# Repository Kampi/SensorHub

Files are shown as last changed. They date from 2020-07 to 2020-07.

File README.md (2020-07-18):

# SensorHub

## Table of Contents

- [SensorHub](#sensorhub)
  - [Table of Contents](#table-of-contents)
  - [About](#about)
  - [Image sources](#image-sources)
  - [Setup](#setup)
  - [Device modes](#device-modes)
  - [Bluetooth](#bluetooth)
  - [Measurement](#measurement)
  - [History](#history)
  - [Maintainer](#maintainer)

## About

Solar-powered, low energy environment sensor node with WiFi interface. The device will measure the following parameter:

- Temperature (with a [MCP9808](http://ww1.microchip.com/downloads/en/DeviceDoc/25095A.pdf))
- Humidity (with a [BME680](https://www.bosch-sensortec.com/media/boschsensortec/downloads/datasheets/bst-bme680-ds001.pdf))
- Pressure (with a [BME680](https://www.bosch-sensortec.com/media/boschsensortec/downloads/datasheets/bst-bme680-ds001.pdf))
- Gas resistance (with a [BME680](https://www.bosch-sensortec.com/media/boschsensortec/downloads/datasheets/bst-bme680-ds001.pdf))
- Ambient light (with a [BH1726](https://fscdn.rohm.com/en/products/databook/datasheet/ic/sensor/light/bh1726nuc-e.pdf))
- UV (with a [VEML6070](https://www.vishay.com/docs/84277/veml6070.pdf))

The whole device is designed for low power operation and for a solar panel as current source. A backup battery will be used to buffer the sun-free time during the night or on cloudy days.
This battery will be charged by an integrated solar-charging circuit.

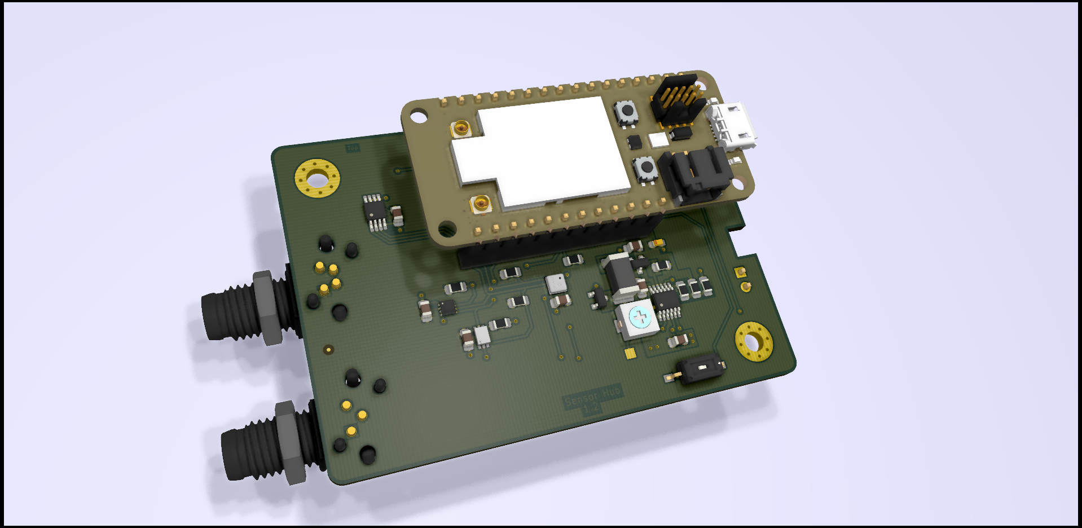
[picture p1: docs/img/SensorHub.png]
Overview


The integrated WiFi is used to transmit the data as an [MQTT](http://mqtt.org/) message to a broker (i. e. a Raspberry Pi). The included Qt application for the Raspberry Pi can be used to visualize and record the received data.

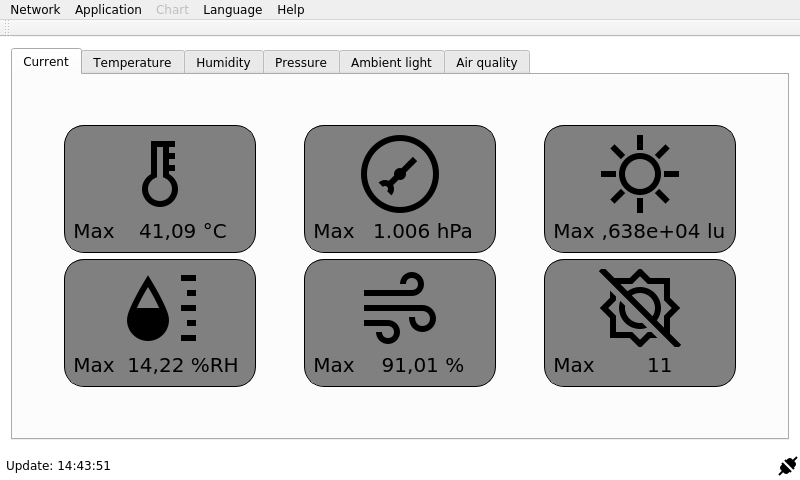
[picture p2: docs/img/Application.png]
Application


Please visit the [project site](https://www.kampis-elektroecke.de/wetterdaten-aufzeichnen/) or write me an [e-mail](mailto:DanielKampert@kampis-elektroecke.de) when you need additional informations or if you have any questions.

## Image sources

- [Language Icons](https://www.iconfinder.com/iconsets/flags_gosquared)
- [Icons8](https://icons8.com/icon/set/database/material)
- [Qt project](https://www.qt.io/blog/2016/06/20/introducing-new-built-with-qt-logo)

## Setup

- You have to use the [Particle CLI](https://docs.particle.io/reference/developer-tools/cli/) or the [Particle App](https://play.google.com/store/apps/details?id=io.particle.android.app&hl=de) to setup your WiFi credentials in the microcontroller module before you can use the software.

```bash
$ particle usb start-listening
Done.

$ particle serial wifi
? Should I scan for nearby Wi-Fi networks? (Y/n) y
? Should I scan for nearby Wi-Fi networks? Yes
? SSID ...
? SSID ...
? Security Type (Use arrow keys)
? Security Type ...
? Cipher Type (Use arrow keys)
? Cipher Type ...
? Wi-Fi Password ...
? Wi-Fi Password ...
Done! Your device should now restart.
```

- Download a bluetooth app for your smartphone (i. e. [nRF Connect](https://play.google.com/store/apps/details?id=no.nordicsemi.android.mcp&hl=de)).
- Make sure that your microcontroller module runs at least firmware version [1.5.2](https://github.com/particle-iot/device-os/releases/tag/v1.5.2).
- **Optional:** Build the firmware from the soures in `software/SensorHub` by using [Visual Studio Code](https://code.visualstudio.com/) and the [Particle Workbench](https://www.particle.io/workbench/).
- Power up the `SensorHub` and flash the firmware from `software/release` by using the [Particle CLI](https://docs.particle.io/tutorials/developer-tools/cli/#flashing-over-serial-for-the-electron).
- Hold the `MODE` button of the microcontroller module to enter the setup mode.
- After entering the setup mode the RGB LED of the device will lights up red.
- Open the app and connect your smartphone with the `SensorHub`. When the connection is successful the RGB LED of the `SensorHub` starts to blink green until you close the connection or a IP address of the MQTT broker was transmitted successfully.

## Device modes

The `SensorHub` use the RGB led of the microcontroller module to display his current state. Each state is encoded in a blink pattern which begins with a **3 seconds** group color.

| **RGB color** | **Group** |
|:---:|:---:|
| Blue | Sensors |
| Green | Network |
| Red | Device |

The group color is followed by the error code which is encoded with a white flashing of the RGB LED. Each flash has a duration of **1 second**.

| **Blink code** | **Sensors** | **Network** | **Device** |
|:---:|:---:|:---:|:---:|
| 1x | Temperature sensor failure. | No valid WiFi credentials found. <br> Please use the [Particle CLI](https://docs.particle.io/reference/developer-tools/cli/) to setup your WiFi credentials. | - |
| 2x | Light sensor failure. | No valid IP address found. | - |
| 3x | Environment sensor failure. | Connection error. | - |
| 4x | UV sensor failure. | Network timeout. | - |
| 5x | Communication error. | - | - |

The current device error is also printed over the serial interface of the microcontroller module or is published over the MQTT tag `sensorhub/errors` (this required valid network settings).

## Bluetooth

The firmware use the following UUIDs for the bluetooth low energy service:

| **UUID** | **Description** |
|:---:|:---:|
| b4250401-fb4b-4746-b2b0-93f0e61122c6 | General service UUID for the BLE service. |
| b4250402-fb4b-4746-b2b0-93f0e61122c6 | Server IP UUID to configure the IP address of the MQTT server. |

## Measurement

After a successful configuration and initialization the device will enter the sleep mode. The microcontroller is woken up every three minutes to read in new data from the sensors. After a successful read of the
sensors the data gets packed in a [JSON](https://www.json.org/json-en.html) structure and published by using the [MQTT](http://mqtt.org/) protocol. The firmware uses the topic `sensorhub/weather` to publish the sensor data in the network.
The JSON object uses the following structure:

```json
{
  "Temperature": "23.0",
  "Ambient light": "1000.0",
  "UV": "7",
  "Pressure": "1004",
  "Humidity": "44.0",
  "Gas resistance": "20000",
  "Gas valid": "0",
  "IAQ": "97.5",
  "IAQ valid": "0",
  "Solar": "1.2",
  "Battery": "3.3"
}
```

| **Element** | **Description** |
|:---:|:---:|
| Temperature | Temperature as float in °C. |
| Ambient light  | Illuminance as float in lux. |
| UV | UV-A index as byte in the range of 0 to 11. |
| Pressure | Air pressure as float in hPa. |
| Humidity | Humidity as float in %RH. |
| Gas resistance | Gas resistance as float in Ohms. |
| Gas valid | Boolean flag to indicate a valid gas measurement. |
| IAQ | [Indor Air Quality](https://en.wikipedia.org/wiki/Indoor_air_quality) in %. |
| IAQ valid | Boolean flag to indicate a valid IAQ index. |
| Solar | Solar cell voltage as float in V. |
| Battery | Battery voltage as float in V. |

## History

| **Version** | **Description** | **Date** |
|---|---|---|
| 0.1 | Release hardware version 1.1 <br> Firmware version 1.0 <br> Release application version 1.0 | 13.07.2020 |
| 0.2 | Release hardware version 1.2 <br> Improve firmware and release firmware 1.1 <br> Release application version 1.1 | 18.07.2020 |

## Maintainer

- [Daniel Kampert](mailto:DanielKampert@kampis-elektroecke.de)

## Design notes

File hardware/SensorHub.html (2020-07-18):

# SensorHub

From: 18.05.2020 15:43:41

Component Count: 35

Ref | Qnty | Value | Footprint | Description | Mfr. | Mfr. Part Nr. | Mouser
C1, C3 | 2 | 1uF | C_0805_2012Metric_Pad1.15x1.40mm_HandSolder | Unpolarized capacitor | Kemet | C0805X105K3RAC3316 | 80-C0805X105K3R3316
C2, C6, C7, C8 | 4 | 100nF | C_0805_2012Metric_Pad1.15x1.40mm_HandSolder | Unpolarized capacitor | Kemet | C0805C104K5RAC7411 | 80-C0805C104K5RACLR
C4, C9 | 2 | 10uF | C_0805_2012Metric_Pad1.15x1.40mm_HandSolder | Unpolarized capacitor | TDK | C2012X7S1E106K125AE | 810-C2012X7S1E106125
C5 | 1 | 100uF | CP_EIA-1608-08_AVX-J_Pad1.25x1.05mm_HandSolder | Polarized capacitor | AVX | F980J107MMAAXE | 581-F980J107MMAAXE
D1, D2 | 2 | ZLLS500 | D_SOT-23_ANK | Schottky diode | Diodes Incorporated | ZLLS500TA | 522-ZLLS500TA
IC1 | 1 | BQ32000 | SOIC-8_3.9x4.9mm_P1.27mm | Serial, I2C Real-time clock, Trickle charger, 3V to 3.6V VCC, -40°C to +85°C, SOIC-8 | Texas Instruments | BQ32000DR | 595-BQ32000DR
IC2 | 1 | LT3652EMSE | MSOP-12-1EP_3x4mm_P0.65mm_EP1.65x2.85mm | Step-down battery charger, Lithium Phosphate ( LiFePO4), Lead (Pb), Lithium+ (Li+) , 4.95V to 32V VDD, -40 to +125 degree Celcius, MSOP-12 | Analog Devices | LT3652EMSE#PBF | 584-LT3652EMSE#PBF
IC3 | 1 | BME680 | Bosch_LGA-8_3x3mm_P0.8mm_ClockwisePinNumbering | 4-in-1 sensor, gas, humidity, pressure, temperature, I2C and SPI interface, 1.71-3.6V, LGA-8 | Bosch Sensortec | BMP680 | 262-BME680
IC4 | 1 | BH1726 | Texas_S-PWSON-N8_EP1.2x2mm | | Rohm Semiconductor | BH1726NUC-E2 | 755-BH1726NUC-E2
IC5 | 1 | MCP9808 | MSOP-8_3x3mm_P0.65mm | ±0.5°C Maximum Accuracy I2C Temperature Sensor. | Microchip | MCP9808T-E/MS | 579-MCP9808T-E/MS
L1 | 1 | 68uH | L_2512_6332Metric_Pad1.52x3.35mm_HandSolder | Inductor | Vishay / Dale | IHLP2525CZER100M11 | 70-IHLP2525CZER100M1
M1 | 1 | ParticleArgon | ParticleArgon | | Particle | ARGNKIT | 465-ARGNKIT
R1, R2 | 2 | 10k | R_0805_2012Metric_Pad1.15x1.40mm_HandSolder | Resistor | TE Connectivity | CRGP0805F10K | 279-CRGP0805F10K
R3 | 1 | NTC | PinHeader_1x02_P2.54mm_Vertical | Resistor | Murata Electronics | NXRT15XH103FA5B040 | 81-NXRT15XH103FA5B040
R4, R6 | 2 | 220k | R_0805_2012Metric_Pad1.15x1.40mm_HandSolder | Resistor | TE Connectivity | CRGP0805F220K | 279-CRGP0805F220K
R5 | 1 | 47k | R_0805_2012Metric_Pad1.15x1.40mm_HandSolder | Resistor | TE Connectivity | CRGP0805F47K | 279-CRGP0805F47K
R7 | 1 | 0R22 | R_0805_2012Metric_Pad1.15x1.40mm_HandSolder | Resistor | Panasonic | ERJ-U6QJR22V | 667-ERJ-U6QJR22V
R8, R9 | 2 | NB | R_0805_2012Metric_Pad1.15x1.40mm_HandSolder | Resistor
R10, R11, R12 | 3 | 3k3 | R_0805_2012Metric_Pad1.15x1.40mm_HandSolder | Resistor | TE Connectivity | CRGP0805F3K3 | 279-CRGP0805F3K3
RV1 | 1 | 10k | Potentiometer_Vishay_TS53YJ_Vertical | Potentiometer | Vishay | TS53YJ103MR10 | 72-TS53YJ-10K
SW1 | 1 | ENABLE | SW_DIP_SPSTx01_Slide_Omron_A6S-110x_W8.9mm_P2.54mm | 1x DIP Switch, Single Pole Single Throw (SPST) switch, small symbol | Omron | A6S-1104-PH | 653-A6S1104PH
X1 | 1 | WIND | 3-2172067-2 | Generic connector, single row, 01x04, script generated (kicad-library-utils/schlib/autogen/connector/) | TE Connectivity | 3-2172067-2 | 571-3-2172067-2
X2 | 1 | SOLAR | 2-2172067-2 | Generic connector, single row, 01x03, script generated (kicad-library-utils/schlib/autogen/connector/) | TE Connectivity | 2-2172067-2 | 571-2-2172067-2
Y1 | 1 | 32kHz | Crystal_SMD_SeikoEpson_MC306-4Pin_8.0x3.2mm | Two pin crystal | Epson Timing | MC-306 32.7680K-A3:ROHS | 732-MC306-32.7KA3R

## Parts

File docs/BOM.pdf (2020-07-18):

## Stückliste Bill of Materials

Nummer Number | Bezeichnung Description | Wert Value | Gehäuse Case | Hersteller Manufacturer | Herstellerbezeichnung Manufacturer's designation | Lieferant Distributor | Bestellnummer Order number | Anzahl Quantity
C3 | Unpolarized capacitor | 1uF | C_0805_2012Metric_Pad1.15x1.40mm_HandSolder | Kemet | C0805X105K3RAC3316 | Mouser | 80-C0805X105K3R3316 | 1
C2, C6, C7, C8 | Unpolarized capacitor | 100nF | C_0805_2012Metric_Pad1.15x1.40mm_HandSolder | Kemet | C0805C104K5RAC7411 | Mouser | 80-C0805C104K5RACLR | 4
C4, C9 | Unpolarized capacitor | 10uF | C_0805_2012Metric_Pad1.15x1.40mm_HandSolder | TDK | C2012X7S1E106K125AE | Mouser | 810-C2012X7S1E106125 | 2
C5 | Polarized capacitor | 100uF | CP_EIA-1608-08_AVX-J_Pad1.25x1.05mm_HandSolder | AVX | F980J107MMAAXE | Mouser | 581-F980J107MMAAXE | 1
D1, D2 | Schottky diode | ZLLS500 | D_SOT-23_ANK | Diodes Incorporated | ZLLS500TA | Mouser | 522-ZLLS500TA | 2
IC1 | UVA sensor | VEML6070 | OPLGA-6 | Vishay Semiconductors | VEML6070 | Mouser | 78-VEML6070 | 1
IC2 | Step-down battery charger | LT3652EMSE | MSOP-12-1EP_3x4mm_P0.65mm_EP1.65x2.85mm | Analog Devices | LT3652EMSE#PBF | Mouser | 584-LT3652EMSE#PBF | 1
IC3 | 4-in-1 sensor, gas, humidity, pressure, temperature | BME680 | Bosch_LGA-8_3x3mm_P0.8mm_ClockwisePinNumbering | Bosch Sensortec | BMP680 | Mouser | 262-BME680 | 1
IC4 | Ambient light sensor | BH1726 | WSON-8-1EP_2x2mm_P0.5mm_EP0.9x1.6mm | Rohm Semiconductor | BH1726NUC-E2 | Mouser | 755-BH1726NUC-E2 | 1
IC5 | Temperature Sensor | MCP9808 | MSOP-8_3x3mm_P0.65mm | Microchip | MCP9808T-E/MS | Mouser | 579-MCP9808T-E/MS | 1
L1 | Inductor | 22uH | L_2512_6332Metric_Pad1.52x3.35mm_HandSolder | Vishay / Dale | IDC2512ER220M | Mouser | 70-IDC2512ER220M | 1
M1 | | ParticleArgon | ParticleArgon | Particle | ARGNKIT | Mouser | 465-ARGNKIT | 1
R1, R2 | Resistor | 10k | R_0805_2012Metric_Pad1.15x1.40mm_HandSolder | TE Connectivity | CRGP0805F10K | Mouser | 279-CRGP0805F10K | 2
R3 | Resistor | NTC | PinHeader_1x02_P2.54mm_Vertical | Murata Electronics | NXRT15XH103FA5B040 | Mouser | 81-NXRT15XH103FA5B40 | 1
R4 | Resistor | 205k ±1% | R_0805_2012Metric_Pad1.15x1.40mm_HandSolder | Rohm Semiconductor | KTR10EZPF2053 | Mouser | 755-KTR10EZPF2053 | 1
R5 | Resistor | 60k4 ±1% | R_0805_2012Metric_Pad1.15x1.40mm_HandSolder | Rohm Semiconductor | KTR10EZPF6042 | Mouser | 755-KTR10EZPF6042 | 1
R6 | Resistor | 220k ±1% | R_0805_2012Metric_Pad1.15x1.40mm_HandSolder | Bourns | CHV0805-FX-2203ELF | Mouser | 652-CHV0805FX2203ELF | 1
R7 | Resistor | 0R22 ±1% | R_0805_2012Metric_Pad1.15x1.40mm_HandSolder | Panasonic | ERJ-U6QJR22V | Mouser | 667-ERJ-U6QJR22V | 1
R8 | Resistor | 120k ±1% | R_0805_2012Metric_Pad1.15x1.40mm_HandSolder | Rohm Semiconductor | KTR10EZPF1203 | Mouser | 755-KTR10EZPF1203 | 1
R9 | Resistor | 20k5 ±1% | R_0805_2012Metric_Pad1.15x1.40mm_HandSolder | Rohm Semiconductor | KTR10EZPF2052 | Mouser | 755-KTR10EZPF2052 | 1
R10, R11, R12, R13, R14, R15 | Resistor | 3k3 | R_0805_2012Metric_Pad1.15x1.40mm_HandSolder | TE Connectivity | CRGP0805F3K3 | Mouser | 279-CRGP0805F3K3 | 6
R16 | Resistor | 270k | R_0805_2012Metric_Pad1.15x1.40mm_HandSolder | TE Connectivity | CRGP0805F270K | Mouser | 279-CRGP0805F270K | 1
RV1 | Potentiometer | 10k | Potentiometer_Vishay_TS53YJ_Vertical | Vishay | TS53YJ103MR10 | Mouser | 72-TS53YJ-10K | 1
SW1 | 1x DIP Switch, Single Pole | ENABLE | SW_DIP_SPSTx01_Slide_Omron_A6S-110x_W8.9mm_P2.54mm | Omron | A6S-1104-PH | Mouser | 653-A6S1104PH | 1
X1 | | WIND | 3-2172067-2 | TE Connectivity | 3-2172067-2 | Mouser | 571-3-2172067-2 | 1
X2 | | SOLAR | 2-2172067-2 | TE Connectivity | 2-2172067-2 | Mouser | 571-2-2172067-2 | 1

Legende / Legend:

Nicht bestückt | Not assembled
Durchsteckmontage | Through-Hole technology

18.07.2020

1.2

Bezeichnung / Name : Sensor Hub

Seite 1 von 4

18.07.2020

1.2

Bezeichnung Description | Hersteller Manufacturer | Herstellerbezeichnung Manufacturer's designation | Lieferant Distributor | Bestellnummer Order number | Anzahl Quantity
Gehäuse, Polycarbonat UL 94 V0, glasklarer Deckel | Bopla | B 080805 PC-V0-G 7024 | Bopla | B 080805 PC-V0-G 7024 | 1
Distanzhülse | Harwin | R30-6701494 | Mouser | 855-R30-6701494 | 2
Druckausgleichselemen | Bopla | DAE M6 7035 | Bopla | DAE M6 7035 | 1
Stecker, Female, 3-pol | TE Connectivity | T4010008031-000 | TE | T4010008031-000 | 1
Stecker, Female, 4-pol | TE Connectivity | T4010008041-000 | TE | T4010008041-000 | 1
Solarzelle | Offgridtec | 002960 | Solar Autark | 3-01-002960 | 1
Schraube M3x18 | | | Würth | SHR-ZYL-ISO14580-A2/70-TX10-M3X18 | 2
Mutter M6x0.75 | TE Connectivity | 1-1634816-0 | RS | 1-1634816-0 | 1

Legende / Legend:

Nicht bestückt | Not assembled

## Mechanische Komponenten Mechanical Components

Bezeichnung / Name: Sensor Hub

## Technische Spezifikationen Technical Specifications

18.07.2020

1.2

Bezeichnung Description | Spezifikation Specification
Abmaße Dimensions | 72 x 50 mm
Standard Standard | IPC-A-610 E Class 2 oder höher IPC-A-610 E Class 2 or higher
Basismaterial Base material | 1,5 mm FR4, 35 µmCu
Stopplack Soldermask | Beidseitig Grün Both sides green
Bestückungsdruck Silkscreen | Keiner None
Oberfläche Surface | Chemisch Nickel-Gold Chemical nickel-gold
Isolierlack Insulation varnish | Nein No
Min. Bohrdurchmesser Min. drill-end diameter | 0,2 mm
Min. Leiterbahnbreite Min track size | 0,25 mm
Min. Leiterbahnabstand Min track distance | 0,2 mm
Kantenmetallisierung Sideplating | Nein No
Freistellung Vias Clearance vias | Bohrlochdurchmesser + max. 0,15 mm gemäß ZVEI Drill hole + max. 0,15 mm regarding ZVEI
Kontur Contour | Gefräst oder geritzt gemäß DIN ISO 2768 mittel Milled or scored according DIN ISO 2768 medium

Bezeichnung / Name: Sensor Hub

## Bestückung Placement

18.07.2020

1.2
Nummer Number | Position X Position X | Position Y Position Y | Seite Side | Rotation Rotation
R8 | -50.419000 | 6.604000 | 0.000000 | bottom
R9 | -54.356000 | 6.604000 | 180.000000 | bottom
C2 | 21.844000 | 15.494000 | 270.000000 | top
C3 | 50.174400 | 18.021400 | 270.000000 | top
C4 | 51.181000 | 24.638000 | 180.000000 | top
C5 | 55.372000 | 24.638000 | 0.000000 | top
C6 | 17.002000 | 20.853400 | 90.000000 | top
C7 | 16.124860 | 36.051480 | 270.000000 | top
C8 | 37.068000 | 18.288000 | 180.000000 | top
C9 | 53.467000 | 8.636000 | 180.000000 | top
D1 | 43.053000 | 17.526000 | 0.000000 | top
D2 | 51.038000 | 21.717000 | 270.000000 | top
IC2 | 53.463700 | 15.125800 | 90.000000 | top
IC3 | 37.068000 | 21.082000 | 90.000000 | top
IC4 | 20.200000 | 20.561400 | 0.000000 | top
IC5 | 13.117860 | 37.139380 | 90.000000 | top
L1 | 46.974000 | 19.980200 | 270.000000 | top
R1 | 40.116000 | 29.426000 | 0.000000 | top
R2 | 35.823000 | 29.426000 | 180.000000 | top
R4 | 56.948800 | 16.245000 | 270.000000 | top
R5 | 59.064400 | 16.245000 | 90.000000 | top
R6 | 61.121800 | 16.245000 | 270.000000 | top
R7 | 54.864000 | 20.828000 | 180.000000 | top
R10 | 30.718000 | 24.130000 | 0.000000 | top
R11 | 30.727000 | 19.558000 | 0.000000 | top
R12 | 40.903000 | 24.384000 | 180.000000 | top
R13 | 44.196000 | 29.438600 | 180.000000 | top
R14 | 22.098000 | 23.368000 | 0.000000 | top
R15 | 28.702000 | 30.226000 | 270.000000 | top
R16 | 27.178000 | 16.764000 | 0.000000 | top
REF** | 3.000000 | 18.000000 | 0.000000 | top
REF** | 70.000000 | 48.000000 | 0.000000 | top

Bezeichnung / Name: Sensor Hub

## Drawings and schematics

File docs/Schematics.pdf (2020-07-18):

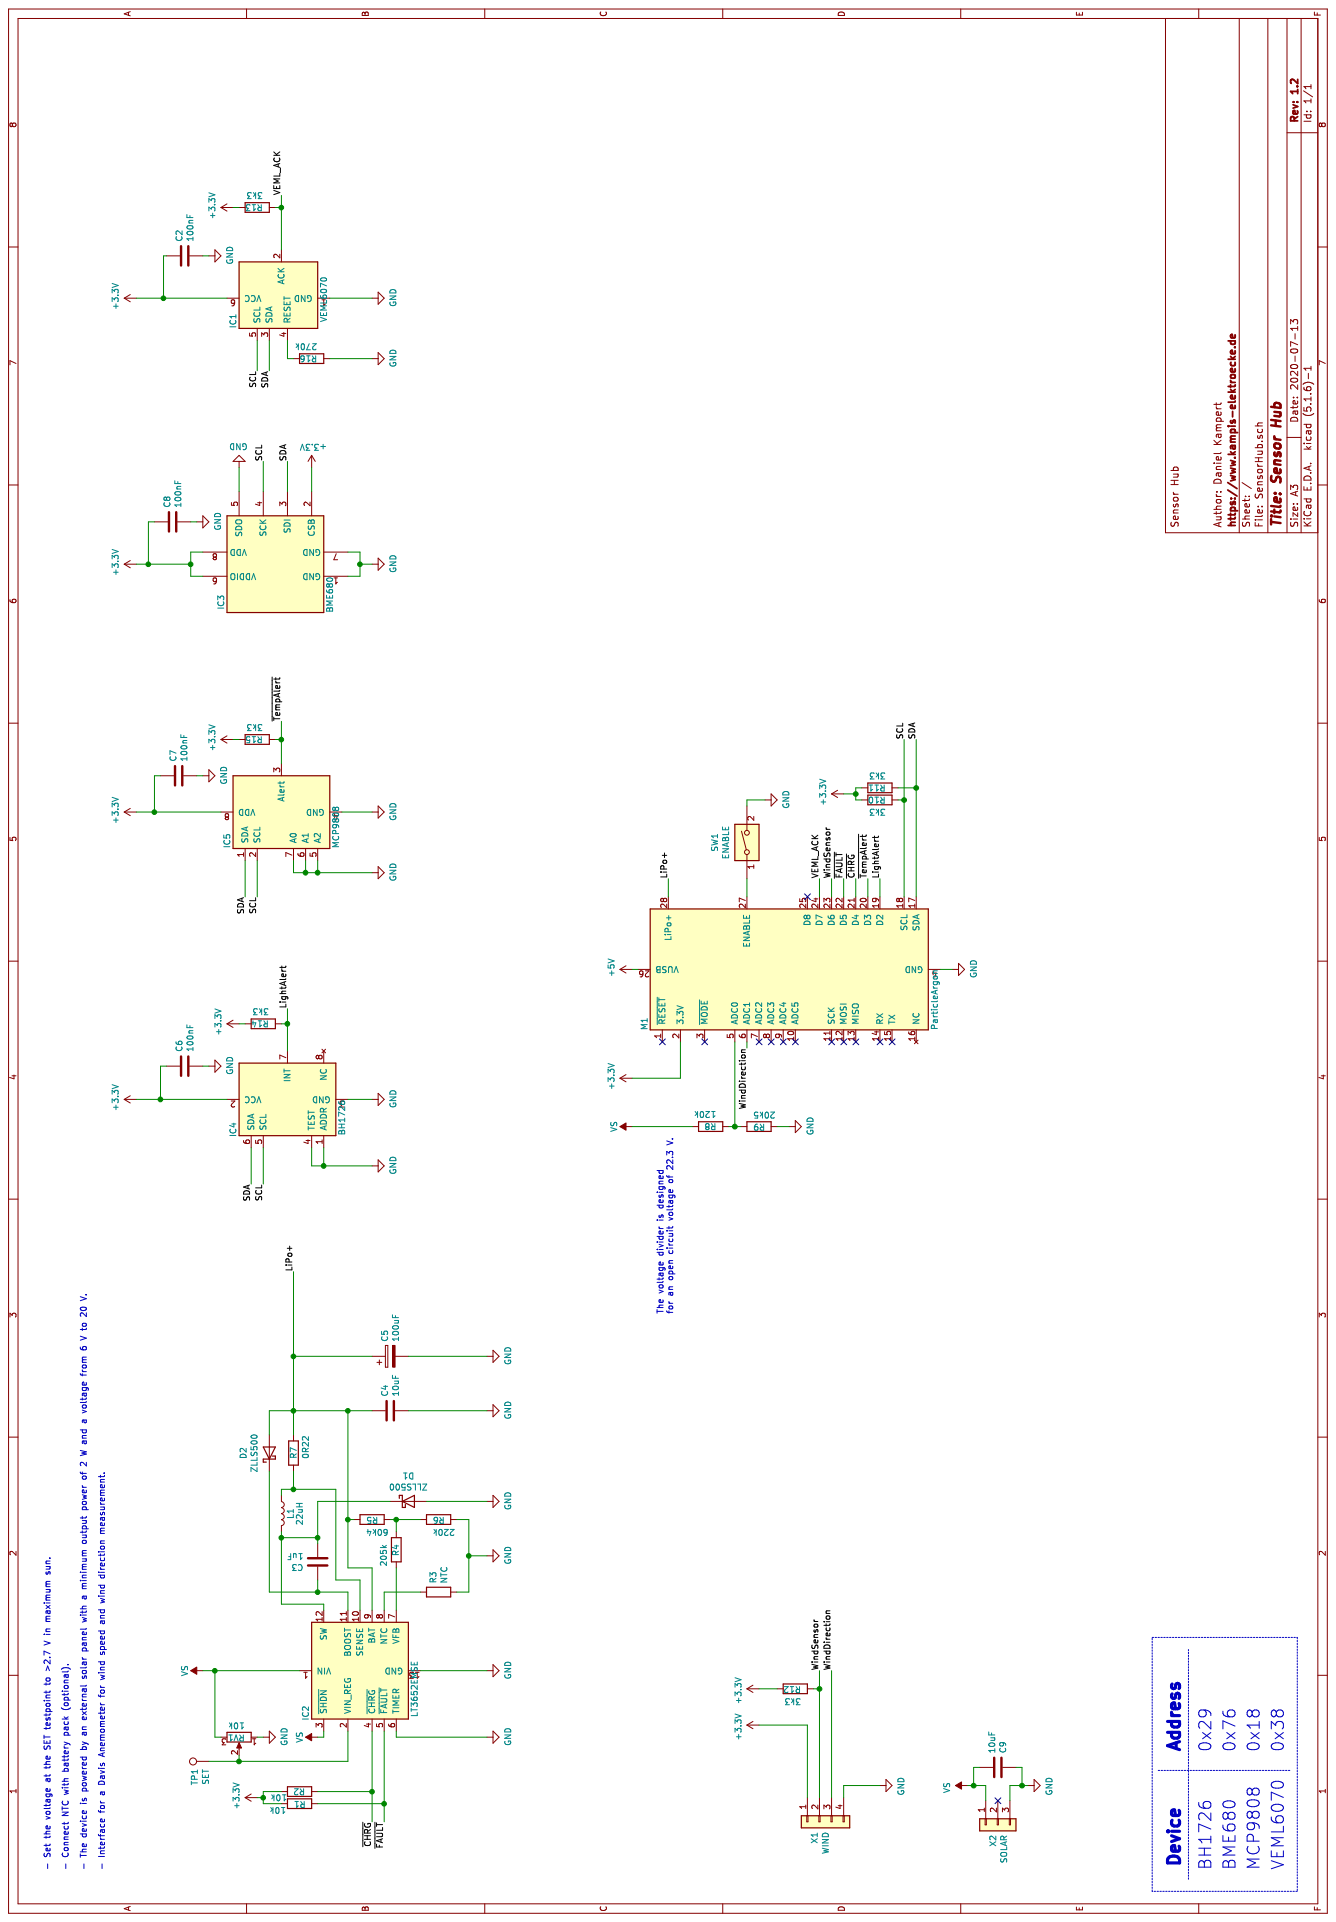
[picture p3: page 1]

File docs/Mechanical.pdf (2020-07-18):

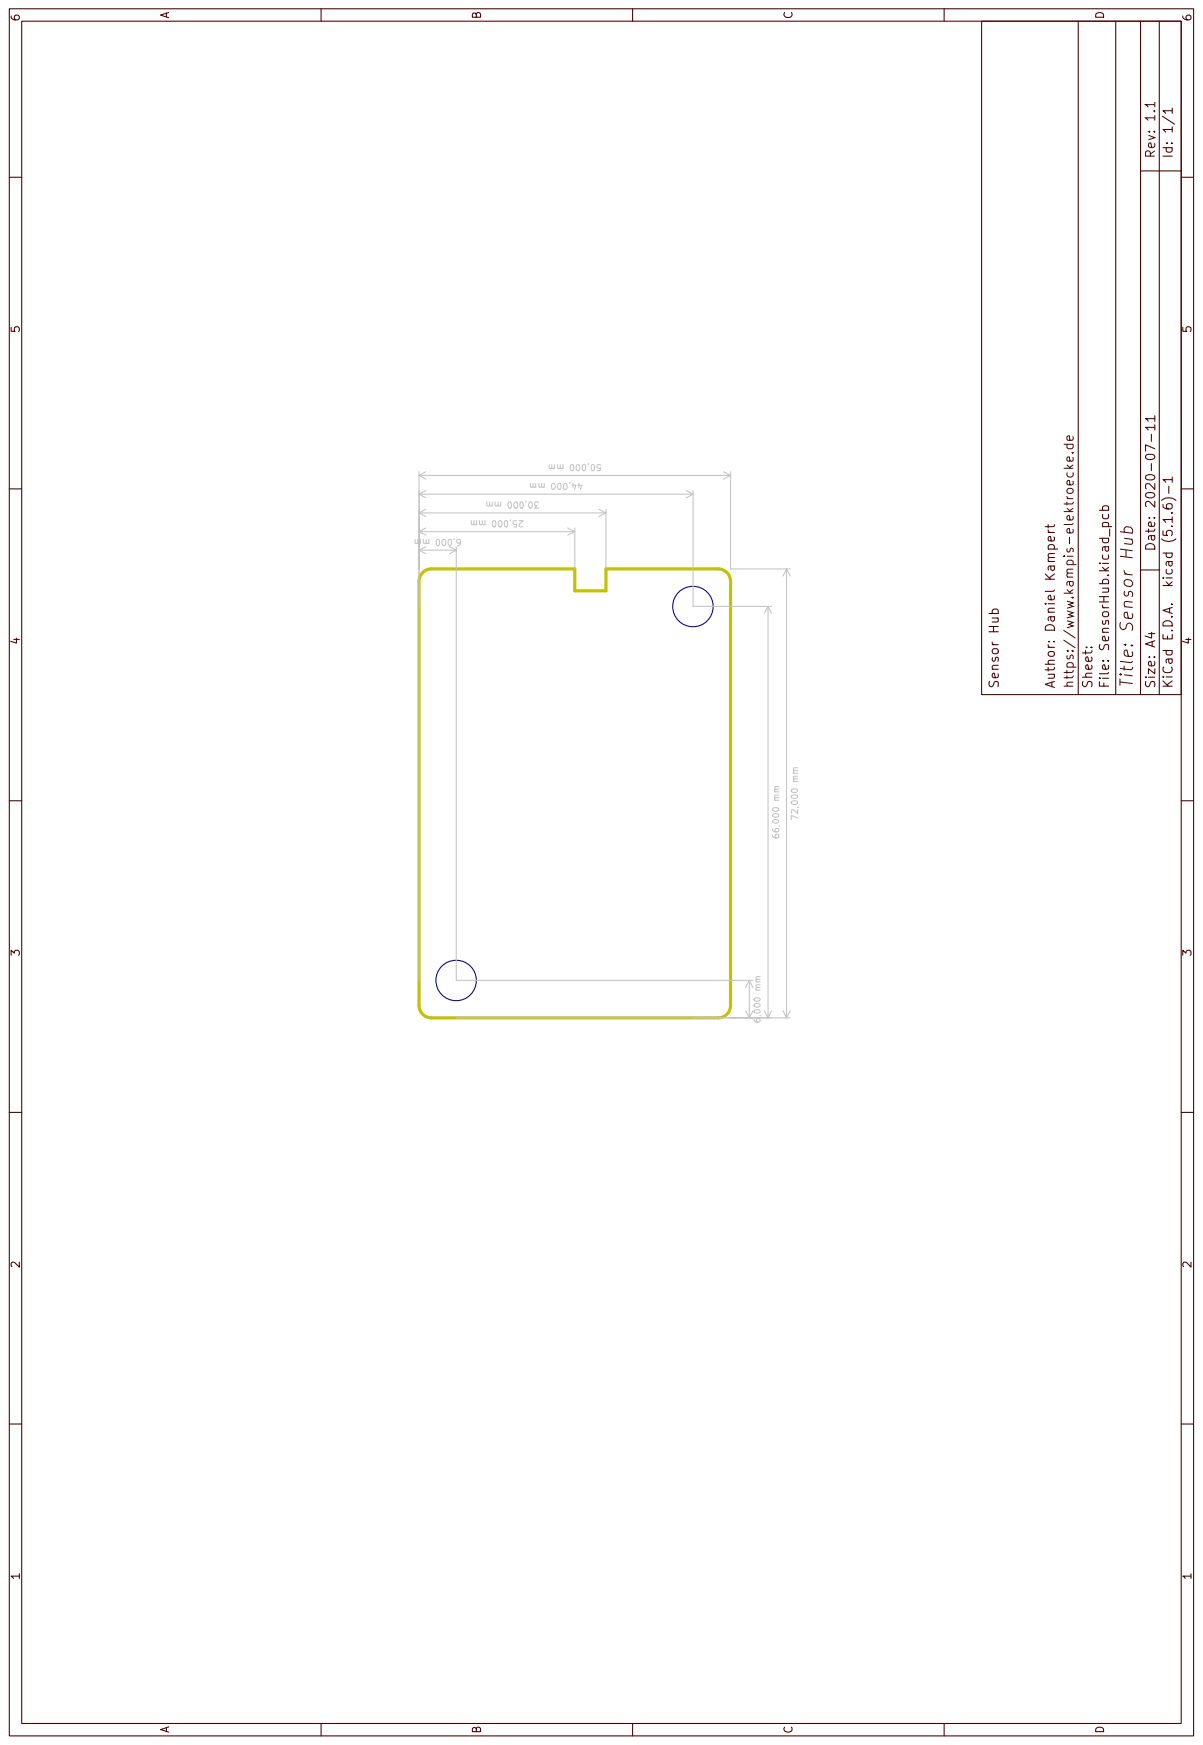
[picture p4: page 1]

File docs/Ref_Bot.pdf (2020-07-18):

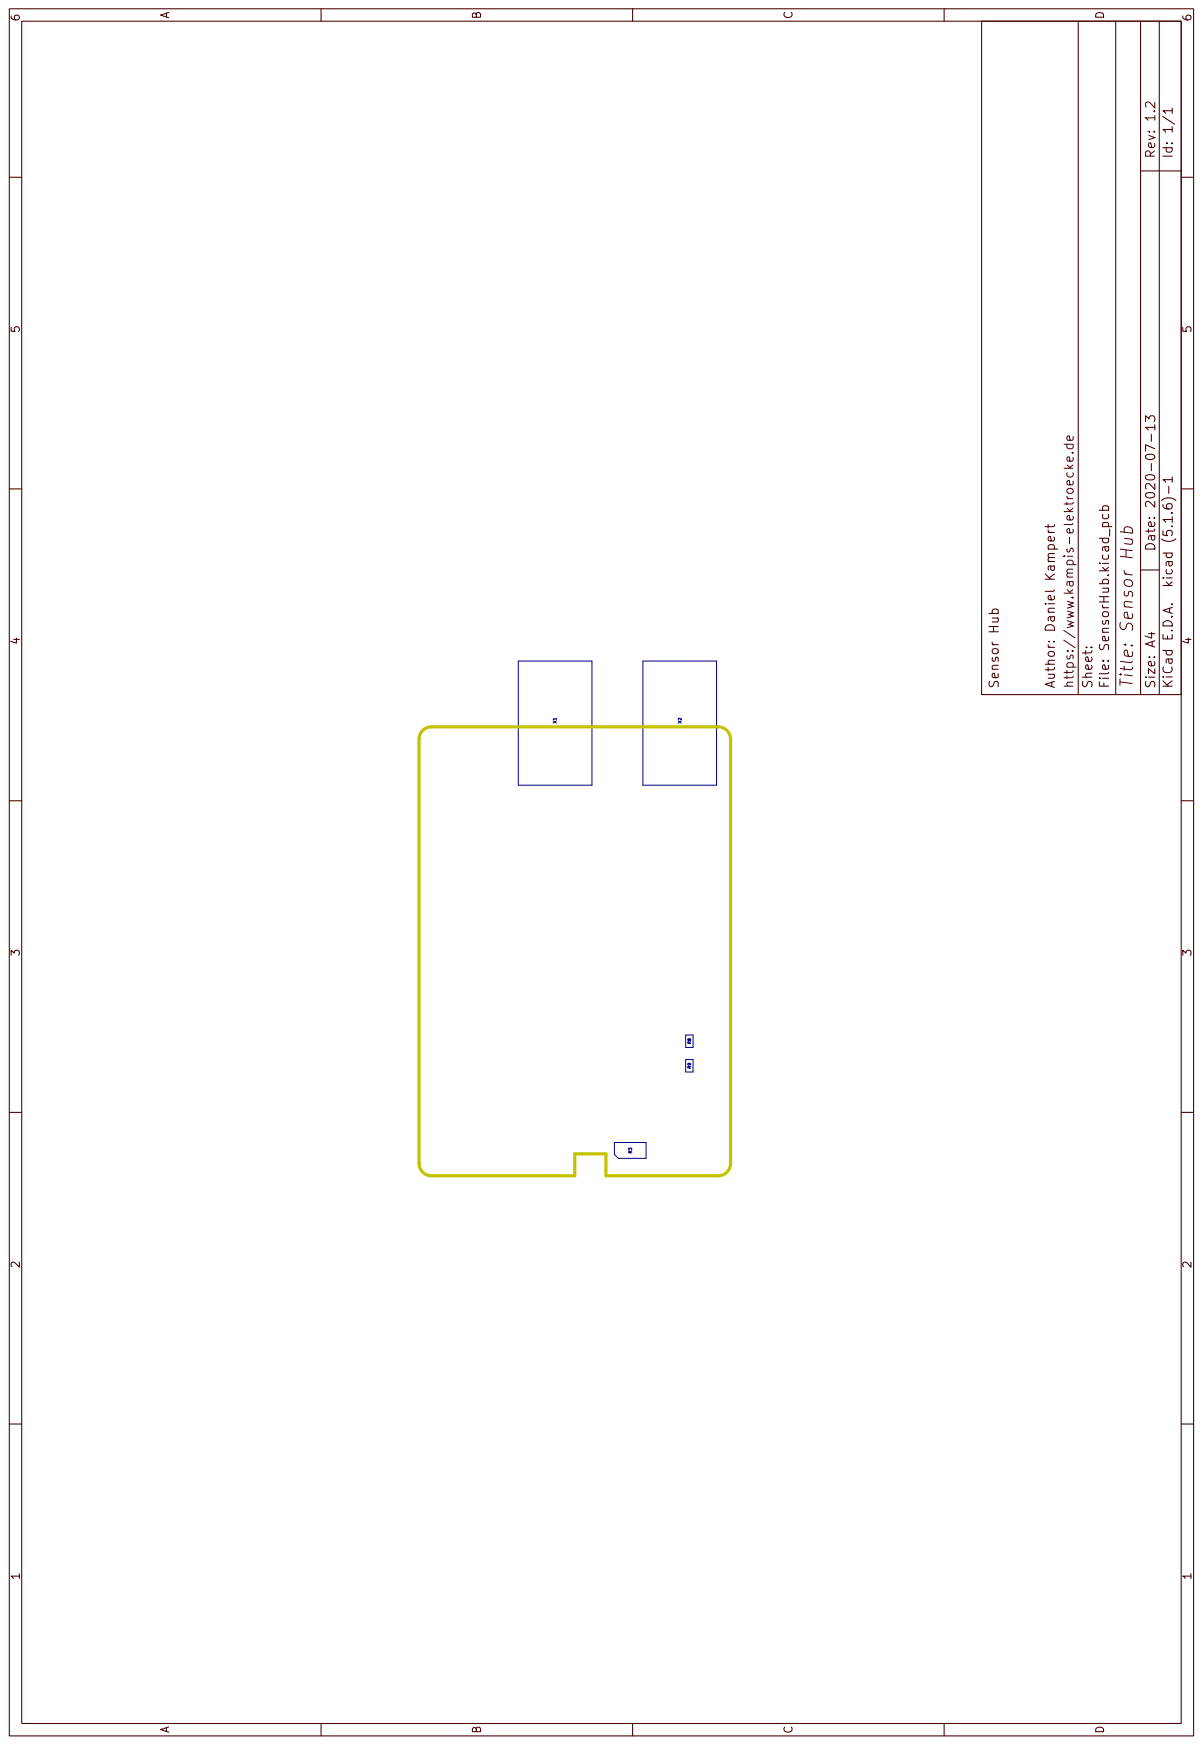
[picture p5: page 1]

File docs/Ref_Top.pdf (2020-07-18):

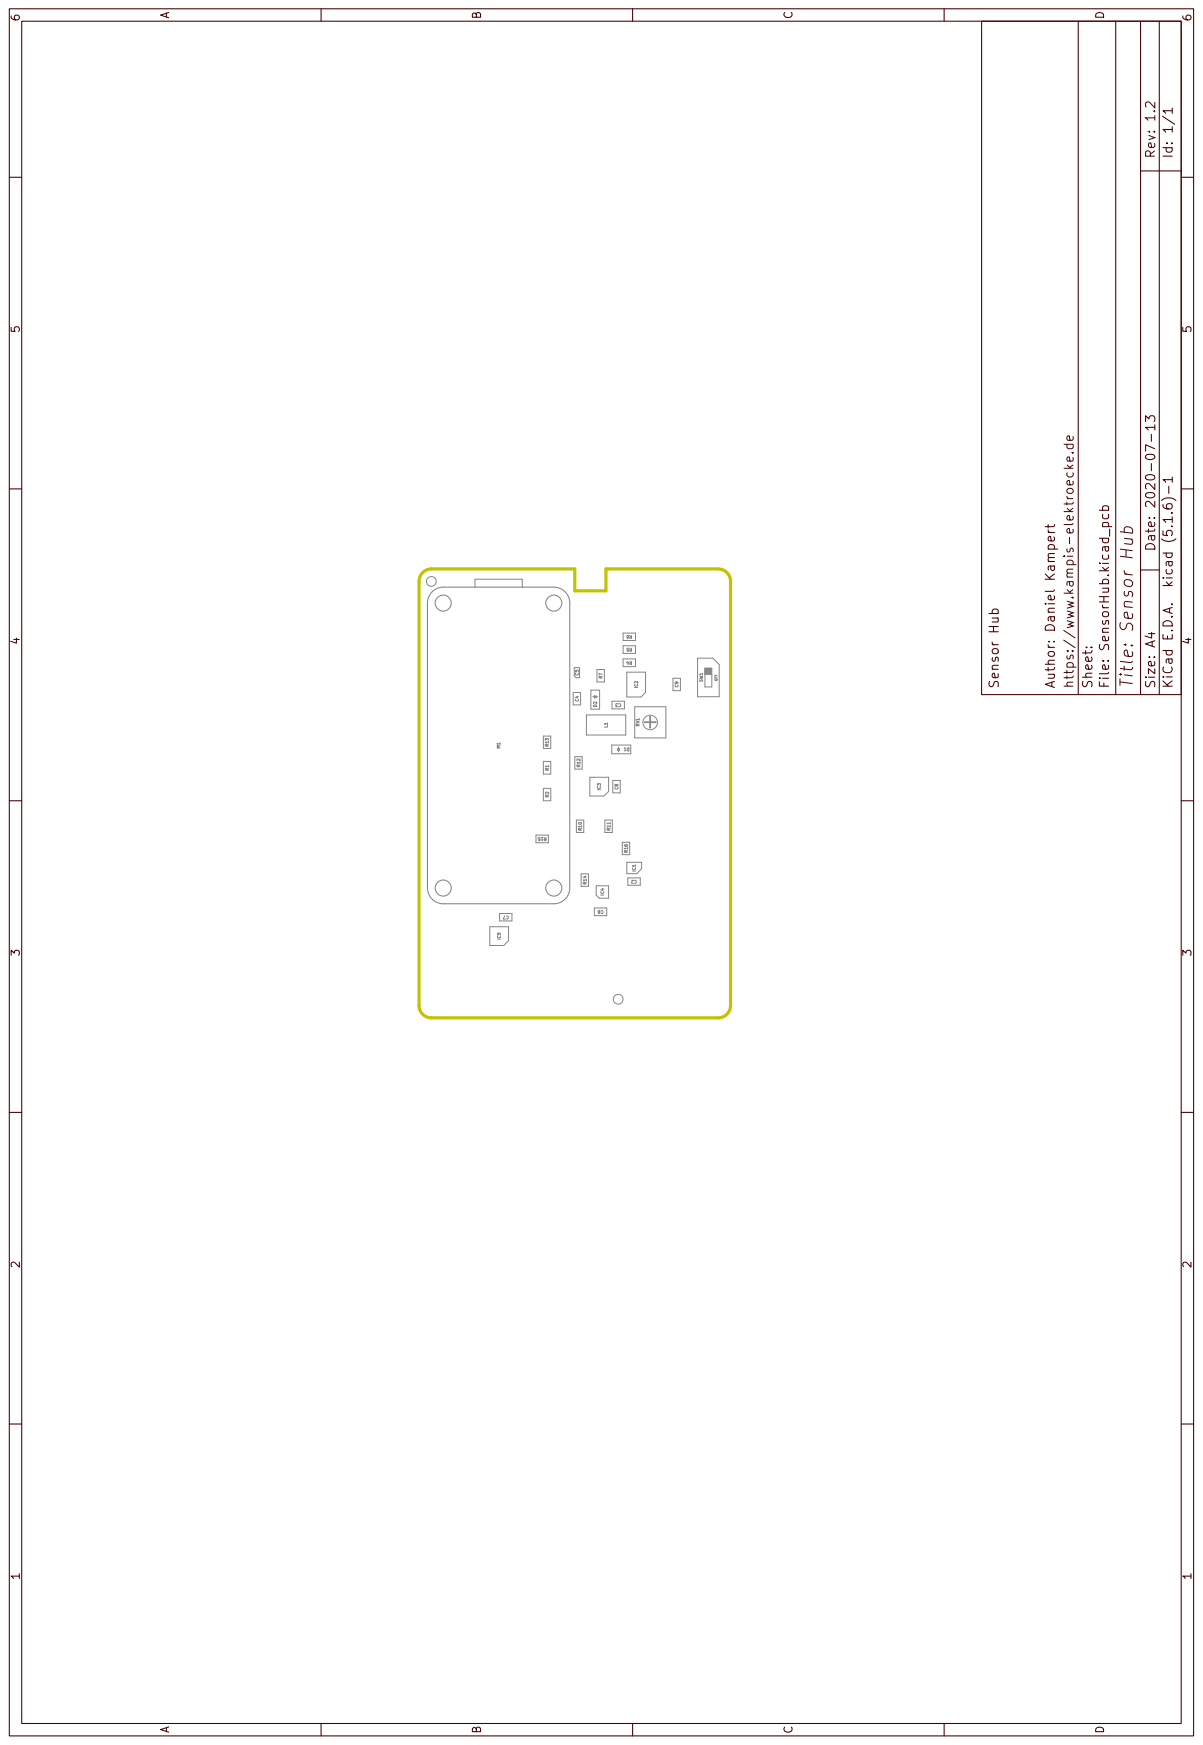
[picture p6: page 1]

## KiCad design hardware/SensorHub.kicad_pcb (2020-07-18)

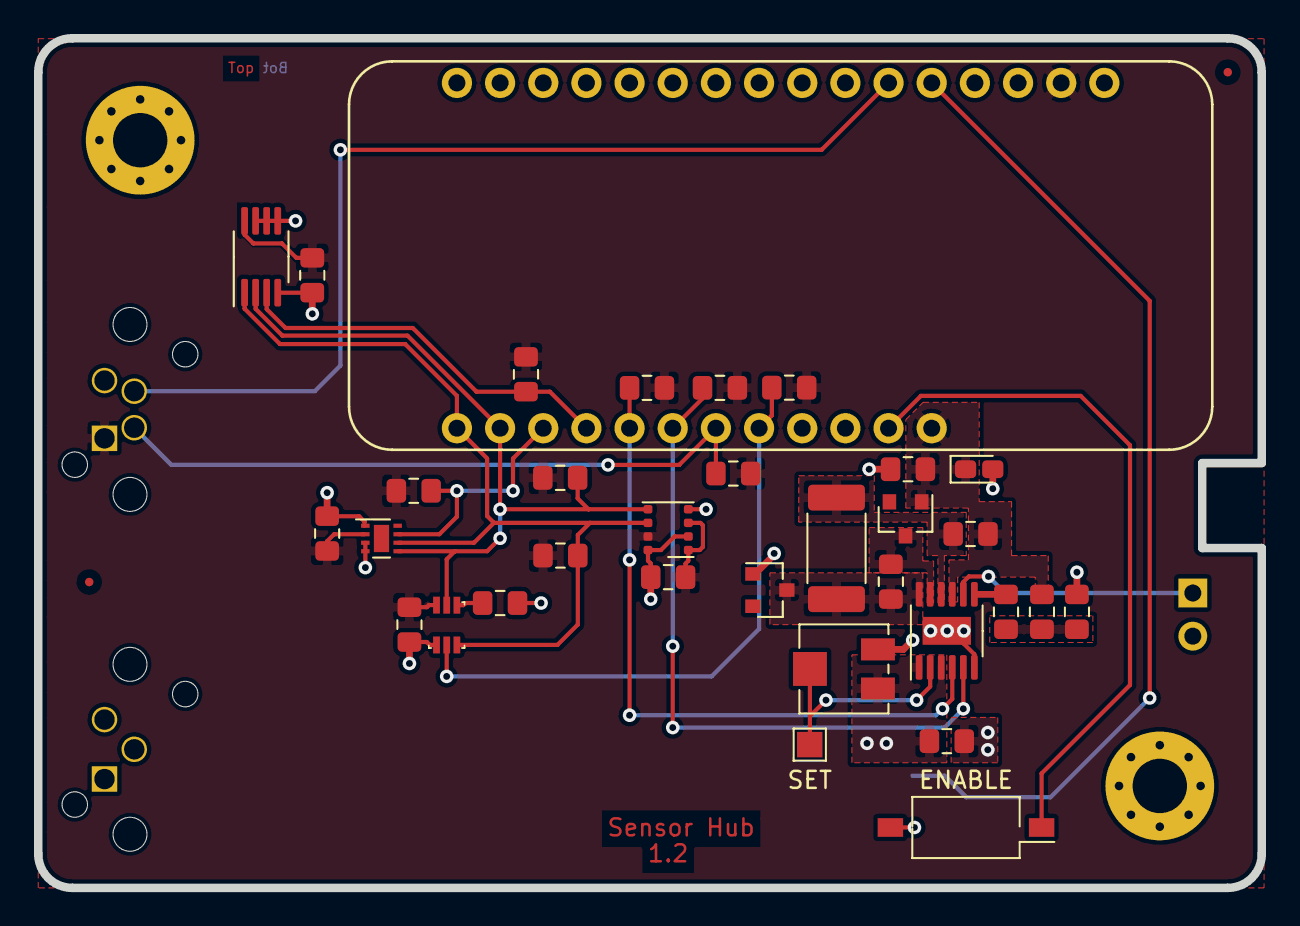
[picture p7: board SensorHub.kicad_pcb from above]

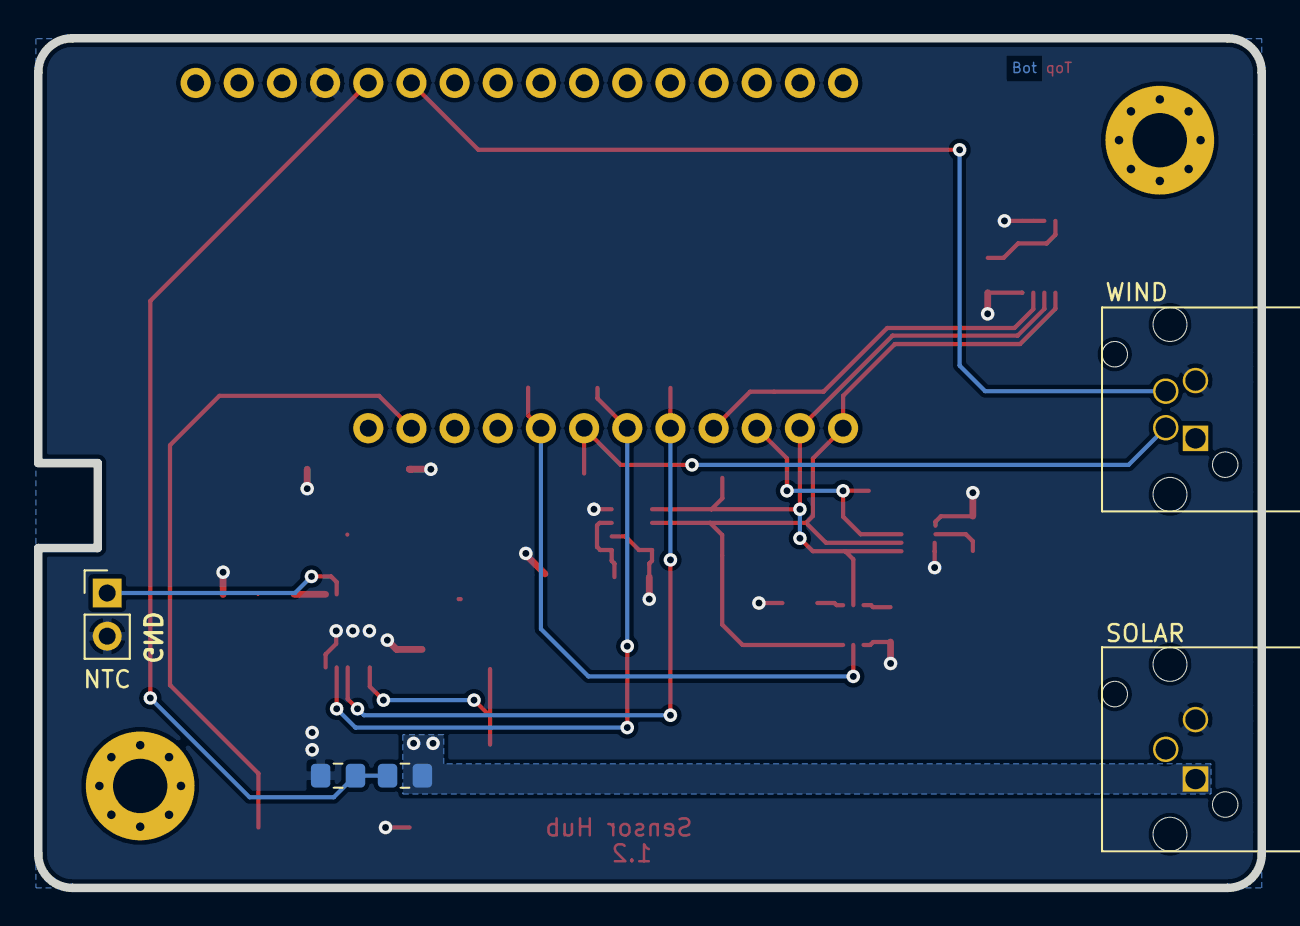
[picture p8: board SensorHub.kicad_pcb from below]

Board: 2 copper layers, 72.0 x 50.0 mm, 38 parts (5 on the bottom side), 23 nets.

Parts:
C2, C6, C7, C8: 100nF; C_0805_2012Metric_Pad1.15x1.40mm_HandSolder
C3: 1uF; C_0805_2012Metric_Pad1.15x1.40mm_HandSolder
C4, C9: 10uF; C_0805_2012Metric_Pad1.15x1.40mm_HandSolder
C5: 100uF; CP_EIA-1608-08_AVX-J_Pad1.25x1.05mm_HandSolder
D1, D2: ZLLS500; D_SOT-23_ANK
IC1: VEML6070; OPLGA-6
IC2: LT3652EMSE; MSOP-12-1EP_3x4mm_P0.65mm_EP1.65x2.85mm
IC3: BME680; Bosch_LGA-8_3x3mm_P0.8mm_ClockwisePinNumbering
IC4: BH1726; WSON-8-1EP_2x2mm_P0.5mm_EP0.9x1.6mm
IC5: MCP9808; MSOP-8_3x3mm_P0.65mm
L1: 68uH; L_2512_6332Metric_Pad1.52x3.35mm_HandSolder
M1: ParticleArgon
R1, R2: 10k; R_0805_2012Metric_Pad1.15x1.40mm_HandSolder
R3: NTC; PinHeader_1x02_P2.54mm_Vertical
R4, R6: 220k; R_0805_2012Metric_Pad1.15x1.40mm_HandSolder
R5: 47k; R_0805_2012Metric_Pad1.15x1.40mm_HandSolder
R7: 0R22; R_0805_2012Metric_Pad1.15x1.40mm_HandSolder
R8: 100k; R_0805_2012Metric_Pad1.15x1.40mm_HandSolder
R9: 22k; R_0805_2012Metric_Pad1.15x1.40mm_HandSolder
R10, R11, R12, R13, R14, R15: 3k3; R_0805_2012Metric_Pad1.15x1.40mm_HandSolder
R16: 270k; R_0805_2012Metric_Pad1.15x1.40mm_HandSolder
RV1: 10k; Potentiometer_Vishay_TS53YJ_Vertical
SW1: ENABLE; SW_DIP_SPSTx01_Slide_Omron_A6S-110x_W8.9mm_P2.54mm
TP1: SET; TestPoint_Pad_1.5x1.5mm
X1: WIND; 3-2172067-2
X2: SOLAR; 2-2172067-2

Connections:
+3V3: C2.1, C6.1, C7.1, C8.1, IC1.6, IC3.2, IC3.6, IC3.8, IC4.2, IC5.8, M1.2, R1.2, R2.1, R10.1, R11.1, R12.1, R13.1, R14.1, R15.1, X1.1
/LiPo+: C4.1, C5.1, D2.2, IC2.9, M1.28, R5.2, R7.1
/LightAlert: IC4.7, M1.19, R14.2
/SCL: IC1.5, IC3.4, IC4.5, IC5.2, M1.18, R10.2
/SDA: IC1.3, IC3.3, IC4.6, IC5.1, M1.17, R11.2
/VEML_ACK: IC1.2, M1.24, R13.2
/WindDirection: M1.6, X1.3
/WindSensor: M1.23, R12.2, X1.2
/~CHRG: IC2.4, M1.21, R2.2
/~FAULT: IC2.5, M1.22, R1.1
/~TempAlert: IC5.3, M1.20, R15.2
GND: C2.2, C4.2, C5.2, C6.2, C7.2, C8.2, C9.1, D1.2, IC1.1, IC2.6, IC2.13, IC3.1, IC3.5, IC3.7, IC4.1, IC4.3, IC4.4, IC5.4, IC5.5, IC5.6, IC5.7, M1.4, R3.2, R6.1, R9.1, R16.2, RV1.1, SW1.2, X1.4, X2.3
unnamed: C3.1, D2.1, IC2.11
unnamed: C3.2, D1.1, IC2.12, L1.2
unnamed: IC1.4, R16.1
unnamed: IC2.2, RV1.2, TP1.1
unnamed: IC2.7, R4.1
unnamed: IC2.8, R3.1
unnamed: IC2.10, L1.1, R7.2
unnamed: M1.5, R8.2, R9.2
unnamed: M1.27, SW1.1
unnamed: R4.2, R5.1, R6.2
VS: C9.2, IC2.1, IC2.3, R8.1, RV1.3, X2.1

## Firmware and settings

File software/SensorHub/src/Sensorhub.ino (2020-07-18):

/*
 * SensorHub.ino
 *
 *  Copyright (C) Daniel Kampert, 2020
 *	Website: www.kampis-elektroecke.de
 *  File info: Application software for the SensorHub.

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
  Errors and omissions should be reported to DanielKampert@kampis-elektroecke.de
 */

#include "Network/Network.h"
#include "Sensors/Sensors.h"
#include "ErrorClass/ErrorClass.h"

#define FIRMWARE_MAJOR                  1
#define FIRMWARE_MINOR                  1
#define FIRMWARE_REVISION               0

#define TIMEOUT                         60000

char Buffer[200];

SystemSleepConfiguration SleepConfig;

SYSTEM_MODE(MANUAL);
SYSTEM_THREAD(ENABLED);

void setup()
{
    delay(3000);

    // Disable LED D7
    pinMode(D7, OUTPUT);
    digitalWrite(D7, LOW);

    Serial.begin(9600);

    Serial.printlnf("--- SensorHub %i.%i.%i ---", FIRMWARE_MAJOR, FIRMWARE_MINOR, FIRMWARE_REVISION);
    Serial.printlnf("[INFO] Device OS version: %s", System.version().c_str());

    if(waitFor(System.buttonPushed, 10000))
    {
        if(Network::Setup(TIMEOUT) != Network::NO_ERROR)
        {
            ErrorClass::DisplayError(ErrorClass::ERROR_NETWORK, Network::lastError());
        }
    }

    Serial.println("[INFO] Initialize system...");
    if((Network::Initialize() != Network::NO_ERROR) || (Sensors::Initialize() != Sensors::NO_ERROR))
    {
        Serial.println("[ERROR] Unable to initialize system!");

        while(1)
        {
            if(Network::lastError() != Network::NO_ERROR)
            {
                ErrorClass::DisplayError(ErrorClass::ERROR_NETWORK, Network::lastError());
            }

            if(Sensors::lastError() != Sensors::NO_ERROR)
            {
                ErrorClass::DisplayError(ErrorClass::ERROR_SENSORS, Sensors::lastError());
            }

            delay(10000);
        }
    }

    SleepConfig.mode(SystemSleepMode::STOP).duration(180s);

    Serial.println("[INFO] Initialization successful! Starting...");
    delay(3000);
}

void loop()
{
    System.sleep(SleepConfig);

    if(Network::Connect(TIMEOUT) == Network::NO_ERROR)
    {
        Sensors::SensorData Data;
        JSONBufferWriter Writer(Buffer, sizeof(Buffer));

        if(Sensors::UpdateData(&Data) == Sensors::NO_ERROR)
        {
            memset(Buffer, 0x00, sizeof(Buffer));
            Writer.beginObject();
                Writer.name("Temperature").value(Data.Temperature);
                Writer.name("Ambient light").value(Data.AmbientLight);
                Writer.name("UV").value(Data.UV);
                Writer.name("Pressure").value(Data.Environment.Pressure);
                Writer.name("Humidity").value(Data.Environment.Humidity);
                Writer.name("Gas resistance").value(Data.Environment.GasResistance);
                Writer.name("Gas valid").value(Data.Environment.GasValid);
                Writer.name("IAQ").value(Data.IAQ.Value);
                Writer.name("IAQ valid").value(Data.IAQ.Valid);
                Writer.name("Solar").value(Data.SolarVoltage);
                Writer.name("Battery").value(Data.BatteryVoltage);
            Writer.endObject();

            Network::Publish("sensorhub/weather", Buffer, sizeof(Buffer));
        }
        else
        {
            ErrorClass::DisplayError(ErrorClass::ERROR_SENSORS, Sensors::lastError());
            String Message(Sensors::lastError());
            Network::Publish("sensorhub/errors", Message);
        }

        Network::Disconnect();
    }
    else
    {
        ErrorClass::DisplayError(ErrorClass::ERROR_NETWORK, Network::lastError());
    }
}

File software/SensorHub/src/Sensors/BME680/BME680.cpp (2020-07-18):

/*
 * BME680.cpp
 *
 *  Copyright (C) Daniel Kampert, 2020
 *	Website: www.kampis-elektroecke.de
 *  File info: Driver for the BME680 I2C environment sensor.

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
  Errors and omissions should be reported to DanielKampert@kampis-elektroecke.de
 */

/** @file BME680/BME680.cpp
 *  @brief Driver for the BME680 I2C environment sensor.
 *
 *  @author Daniel Kampert
 */

#include "BME680.h"

#define BME680_REGISTER_CONFIG				0x75
#define BME680_REGISTER_CTRL_MEAS			0x74
#define BME680_REGISTER_STATUS				0x73
#define BME680_REGISTER_CTRL_HUM			0x72
#define BME680_REGISTER_CTRL_GAS_1			0x71
#define BME680_REGISTER_CTRL_GAS_0			0x70
#define BME680_REGISTER_GAS_WAIT_0		    0x64
#define BME680_REGISTER_RES_HEAT_0		    0x5A
#define BME680_REGISTER_IDAC_HEAT_0	        0x50
#define BME680_REGISTER_GAS_R_LSB 			0x2B
#define BME680_REGISTER_GAS_R_MSB 			0x2A
#define BME680_REGISTER_HUM_LSB 			0x26
#define BME680_REGISTER_HUM_MSB 			0x25
#define BME680_REGISTER_TEMP_XLSB 			0x24
#define BME680_REGISTER_TEMP_LSB 			0x23
#define BME680_REGISTER_TEMP_MSB 			0x22
#define BME680_REGISTER_PRESS_XLSB			0x21
#define BME680_REGISTER_PRESS_LSB			0x20
#define BME680_REGISTER_PRESS_MSB			0x1F
#define BME680_REGISTER_EAS_STATUS			0x1D
#define BME680_REGISTER_SOFT_RESET			0xE0
#define BME680_REGISTER_ID					0xD0

#define BME680_BIT_GAS_MEASURE				0x06
#define BME680_BIT_MEASURE					0x05
#define BME680_BIT_RUN_GAS					0x04
#define BME680_BIT_GAS_VALID				0x05
#define BME680_BIT_HEAT_STAB				0x04
#define BME680_BIT_HEAT_OFF 				0x03

#define BME680_ID                           0x61

#define BME680_ADDRESS                      0x76

bool BME680::initialized(void) const
{
    return this->_mInitialized;
}

uint8_t BME680::id(void) const
{
    return this->_mID;
}

BME680::CalibCoef BME680::calibCoef(void) const
{
    return this->_mCalibCoef;
}

BME680::Error BME680::filter(BME680::Filter* Filter)
{
    uint8_t Temp;

    if(!this->_mInitialized)
    {
        return NOT_INITIALIZED;
    }

    if(Filter == NULL)
    {
        return INVALID_PARAMETER;
    }

    if(this->_readBytes(BME680_REGISTER_CONFIG, &Temp, 1))
    {
	    return this->_mError;
    }

    *Filter = (BME680::Filter)(Temp & 0x07);

    return NO_ERROR;
}

BME680::Error BME680::mode(BME680::Mode* Mode)
{
    uint8_t Temp;

    if(!this->_mInitialized)
    {
        return NOT_INITIALIZED;
    }

    if(Mode == NULL)
    {
        return INVALID_PARAMETER;
    }

    if(this->_readBytes(BME680_REGISTER_CTRL_MEAS, &Temp, 1))
    {
	    return TRANSMISSION_ERROR;
    }

    *Mode = (BME680::Mode)(Temp & 0x03);

    return NO_ERROR;
}

BME680::BME680(void)
{
    this->_mInitialized = false;
}

BME680::~BME680(void)
{
}

BME680::Error BME680::Initialize(bool SDO)
{
    _mAddress = BME680_ADDRESS | ((SDO & 0x01) << 0x00);

    if(!Wire.isEnabled())
    {
        Wire.begin();
    }

    _mInitialized = true;

    this->_readBytes(BME680_REGISTER_ID, &_mID, sizeof(_mID));

    if(_mID != BME680_ID)
    {
        _mInitialized = false;

        return NO_DEVICE;
    }

    if(this->_readCalibCoef())
    {
        _mInitialized = false;

        return this->_mError;
    }

    return NO_ERROR;
}

BME680::Error BME680::SwitchHeater(bool Enable)
{
    return this->_writeByte(BME680_REGISTER_CTRL_GAS_0, ((!Enable) & 0x01) << BME680_BIT_HEAT_OFF);
}

BME680::Error BME680::SetMode(BME680::Mode Mode)
{
    uint8_t Temp;

    if(this->_readBytes(BME680_REGISTER_CTRL_MEAS, &Temp, sizeof(Temp)))
    {
	    return this->_mError;
    }

	Temp &= ~0x03;
	Temp |= (Mode & 0x03);

    return this->_writeByte(BME680_REGISTER_CTRL_MEAS, Temp);
}

BME680::Error BME680::SetFilter(BME680::Filter Filter)
{
    uint8_t Temp;

    if(this->_readBytes(BME680_REGISTER_CONFIG, &Temp, sizeof(Temp)))
    {
	    return this->_mError;
    }

	Temp &= ~0x1C;
	Temp |= ((Filter & 0x03) << 0x02);

    return this->_writeByte(BME680_REGISTER_CONFIG, Temp);
}

BME680::Error BME680::MeasureTemperature(float* Temperature)
{
    return this->MeasureTemperature(Temperature, BME680::X1);
}

BME680::Error BME680::MeasureTemperature(float* Temperature, BME680::OSS OSS_Temperature)
{
    uint32_t RawTemp;

    if(Temperature == NULL)
    {
        return INVALID_PARAMETER;
    }

    if(this->_readTemperature(OSS_Temperature, &RawTemp))
    {
        return this->_mError;
    }

    this->_calcTemperature(RawTemp, Temperature);

    return NO_ERROR;
}

BME680::Error BME680::MeasurePressure(float* Pressure)
{
    return this->MeasurePressure(Pressure, BME680::X1, BME680::X1);
}

BME680::Error BME680::MeasurePressure(float* Pressure, BME680::OSS OSS_Pressure)
{
    return this->MeasurePressure(Pressure, OSS_Pressure, BME680::X1);
}

BME680::Error BME680::MeasurePressure(float* Pressure, BME680::OSS OSS_Pressure, BME680::OSS OSS_Temperature)
{
    float Temperature;
    uint32_t RawPressure;

    if(Pressure == NULL)
    {
        return INVALID_PARAMETER;
    }

    if(this->MeasureTemperature(&Temperature) || this->_readPressure(OSS_Pressure, &RawPressure))
    {
        return this->_mError;
    }

    this->_calcPressure(RawPressure, Pressure);

    return NO_ERROR;
}

BME680::Error BME680::MeasureHumidity(float* Humidity)
{
    return this->MeasureHumidity(Humidity, BME680::X1, BME680::X1);
}

BME680::Error BME680::MeasureHumidity(float* Humidity, BME680::OSS OSS_Humidity)
{
    return this->MeasureHumidity(Humidity, OSS_Humidity, BME680::X1);
}

BME680::Error BME680::MeasureHumidity(float* Humidity, BME680::OSS OSS_Humidity, BME680::OSS OSS_Temperature)
{
    float Temperature;
    uint16_t RawHumidity;

    if(Humidity == NULL)
    {
        return INVALID_PARAMETER;
    }

    if(this->MeasureTemperature(&Temperature) || this->_readHumidity(OSS_Humidity, &RawHumidity))
    {
        return this->_mError;
    }

    this->_calcHumidity(RawHumidity, Humidity);

    return NO_ERROR;
}

BME680::Error BME680::MeasureGas(BME680_Heater Profile, float* GasResistance, bool* Valid)
{
    uint16_t GasADC;
    uint8_t GasRange;

    if((GasResistance == NULL) || (Valid == NULL))
    {
        return INVALID_PARAMETER;
    }

    if(this->_readGas(Profile, &GasADC, &GasRange, Valid))
    {
        return this->_mError;
    }

    this->_calcGasResistance(GasADC, GasRange, GasResistance);

    return NO_ERROR;
}

BME680::Error BME680::Measure(BME680_Heater Profile, BME680::Data* Data)
{
    return this->Measure(Profile, Data, BME680::X1, BME680::X1, BME680::X1);
}
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

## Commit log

2020-07-13 Recreate for clean up
    [BOM.xlsx, SensorHub.kicad_pcb, SensorHub.sch]
2020-07-13 Clean up hardware files
    [BOM.xlsx, SensorHub.kicad_pcb, SensorHub.sch]
2020-07-13 Init branch
    [BOM.xlsx, SensorHub.sch]
2020-07-13 Optimize LTC3652 layout
    [BOM.xlsx, SensorHub.kicad_pcb, SensorHub.sch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]
2020-07-13 Remove pick & place file
    [SensorHub-all-pos.csv]
2020-07-14 Update README, BOM and schematics
    [SensorHub.sch]
2020-07-14 Add solar voltage measurement to 'Sensors' class and to MQTT message
2020-07-15 Fix wrong footprint for 'power' and 'wind' connector
    [SensorHub.csv, SensorHub.kicad_pcb, SensorHub.sch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]
2020-07-15 - Add battery voltage measurement to MQTT message - Create new firmware release - Update README
2020-07-18 Release hardware version 1.2
    [BOM.xlsx, SensorHub.csv, SensorHub.kicad_pcb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]
2020-07-18 - Change the values of the three feedback resistors ('R4', 'R5' and 'R6')
    [BOM.xlsx, SensorHub.sch]
2020-07-18 Change values for 'R8' and 'R9' to support 20 V solar cells
    [BOM.xlsx, SensorHub.csv, SensorHub.sch]
2020-07-18 - Change 'R5' to 60.4k Ohms
    [BOM.xlsx, SensorHub.csv, SensorHub.sch]

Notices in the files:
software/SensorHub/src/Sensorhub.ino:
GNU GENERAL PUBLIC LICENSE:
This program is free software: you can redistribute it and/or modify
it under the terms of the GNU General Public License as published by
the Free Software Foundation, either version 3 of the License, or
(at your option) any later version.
